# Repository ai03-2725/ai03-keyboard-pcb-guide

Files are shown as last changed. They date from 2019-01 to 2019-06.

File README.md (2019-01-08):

# ai03's Keyboard PCB guide

* The guide covers everything from installing KiCad to producing the PCB.
* [Read it here](https://kbwiki.ai03.me/books/pcb-design/chapter/pcb-designer-guide)

### Repo contents
The repository contains the latest version of a PCB built following the guide.
Feel free to take a look if you need some help.

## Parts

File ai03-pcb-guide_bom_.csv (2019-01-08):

Component | Description | Part | References | Value | Footprint | Quantity Per PCB | Datasheet
1 | Unpolarized capacitor | C_Small | C4 C5 C6 | 0.1uF | C_0805 | 3 | ~
2 | Unpolarized capacitor | C_Small | C7 | 10uF | C_0805 | 1 | ~
3 | Unpolarized capacitor | C_Small | C3 | 1uF | C_0805 | 1 | ~
4 | Unpolarized capacitor | C_Small | C1 C2 | 22pF | C_0805 | 2 | ~
5 | Diode, small symbol | D_Small | D1 D2 D3 D4 | SOD-123 | D_SOD-123 | 4 | ~
6 | resettable fuse, polymeric positive temperature coefficient (PPTC), small symbol | Polyfuse_Small | F1 | 500mA | Fuse_SMD1206_Reflow | 1 | ~
7 |  | MX-1U | MX1 MX2 MX3 MX4 | MX-1U | MX-1U | 4
8 | Resistor, small symbol | R_Small | R1 R4 | 10k | R_0805 | 2 | ~
9 | Resistor, small symbol | R_Small | R2 R3 | 22 | R_0805 | 2 | ~
10 | Push button switch, generic, two pins | SW_Push | SW1 | SW_Push | SKQG-1155865 | 1
11 | 16MHz, 16kB Flash, 1.25kB SRAM, 512B EEPROM, USB 2.0, TQFP-44 | ATmega32U4-AU | U1 | ATmega32U4-AU | TQFP-44_10x10mm_Pitch0.8mm | 1 | http://ww1.microchip.com/downloads/en/DeviceDoc/Atmel-7766-8-bit-AVR-ATmega16U4-32U4_Datasheet.pdf
12 |  | Molex-0548190589 | USB1 | Molex-0548190589 | Molex-0548190589-Assembly | 1
13 | Four pin crystal, two ground/package pins (pin2 and 4) small symbol | Crystal_GND24_Small | Y1 | 16MHz | Crystal_SMD_3225-4pin_3.2x2.5mm | 1 | ~
Component Groups: | 13
Component Count: | 24
Fitted Components: | 24
Number of PCBs: | 1
Total components: | 24
Schematic Version:
Schematic Date:
BoM Date: | 1/7/2019 21:46
Schematic Source:
KiCad Version: | Eeschema (5.0.0)

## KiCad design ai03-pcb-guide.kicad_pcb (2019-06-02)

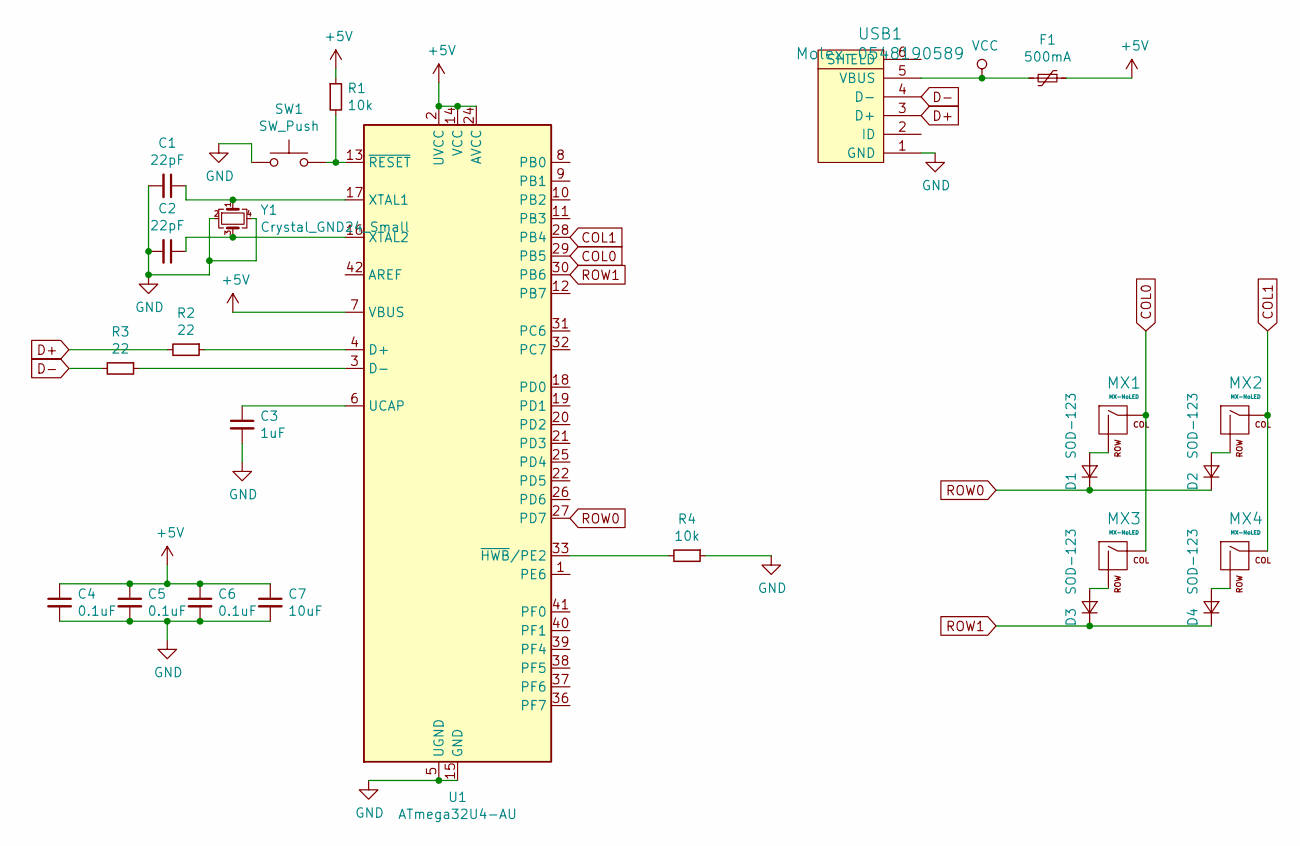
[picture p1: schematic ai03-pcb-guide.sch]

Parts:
C1, C2: 22pF; C_0805
C3: 1uF; C_0805
C4, C5, C6: 0.1uF; C_0805
C7: 10uF; C_0805
D1, D2, D3, D4: SOD-123; D_SOD-123
F1: 500mA; Fuse_SMD1206_Reflow
MX1, MX2, MX3, MX4: MX-NoLED; MX-1U
R1, R4: 10k; R_0805
R2, R3: 22; R_0805
SW1: SW_Push; SKQG-1155865
U1: ATmega32U4-AU; TQFP-44_10x10mm_Pitch0.8mm
USB1: Molex-0548190589; Molex-0548190589-Assembly
Y1: Crystal_GND24_Small; Crystal_SMD_3225-4pin_3.2x2.5mm

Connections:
+5V: C4.1, C5.1, C6.1, C7.1, F1.1, R1.1, U1.2 (UVCC), U1.7 (VBUS), U1.14 (VCC), U1.24 (AVCC), U1.34 (VCC), U1.44 (AVCC)
COL0: MX1.1 (COL), MX3.1 (COL), U1.29 (PB5)
COL1: MX2.1 (COL), MX4.1 (COL), U1.28 (PB4)
D+: R2.2, USB1.3 (D+)
D-: R3.2, USB1.4 (D-)
GND: C1.2, C2.2, C3.2, C4.2, C5.2, C6.2, C7.2, R4.1, SW1.1, U1.5 (UGND), U1.15 (GND), U1.23 (GND), U1.35 (GND), U1.43 (GND), USB1.1 (GND), Y1.2, Y1.4
unnamed: C1.1, U1.17 (XTAL1), Y1.1
unnamed: C2.1, U1.16 (XTAL2), Y1.3
unnamed: C3.1, U1.6 (UCAP)
unnamed: D1.2 (A), MX1.2 (ROW)
unnamed: D2.2 (A), MX2.2 (ROW)
unnamed: D3.2 (A), MX3.2 (ROW)
unnamed: D4.2 (A), MX4.2 (ROW)
unnamed: R1.2, SW1.2, U1.13 (~RESET)
unnamed: R2.1, U1.4 (D+)
unnamed: R3.1, U1.3 (D-)
unnamed: R4.2, U1.33 (~HWB~/PE2)
ROW0: D1.1 (K), D2.1 (K), U1.27 (PD7)
ROW1: D3.1 (K), D4.1 (K), U1.30 (PB6)
VCC: F1.2, USB1.5 (VBUS)

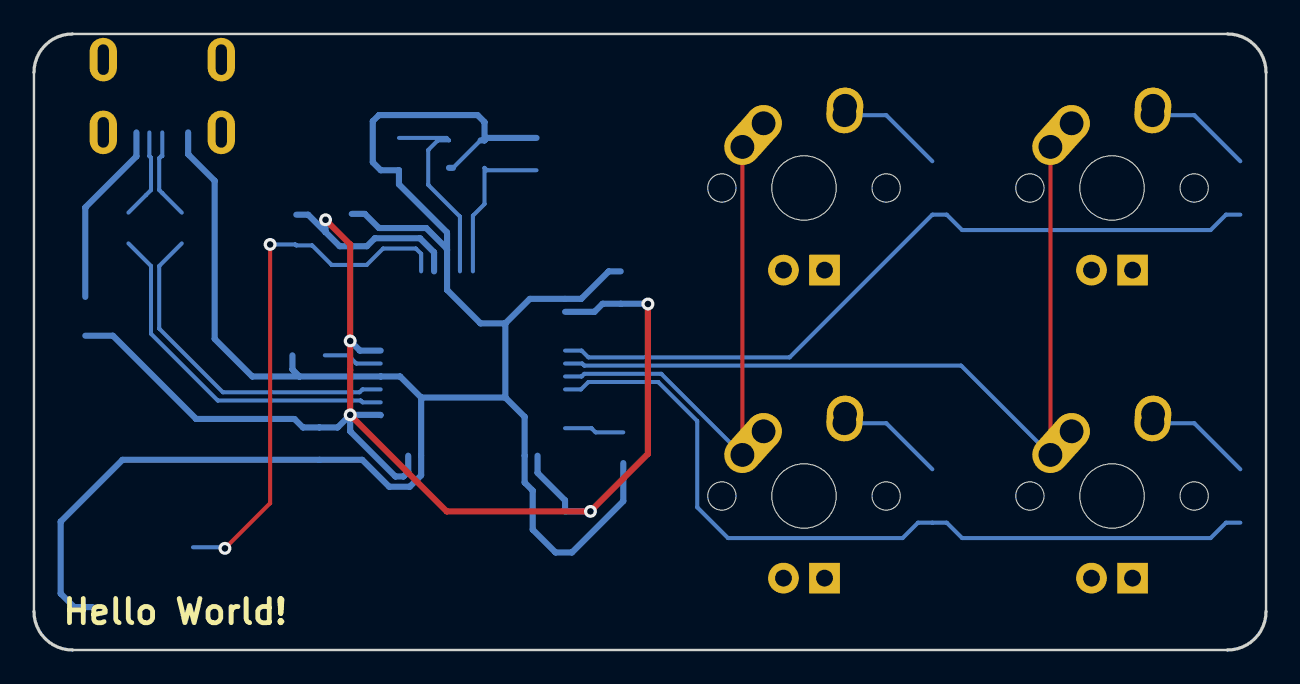
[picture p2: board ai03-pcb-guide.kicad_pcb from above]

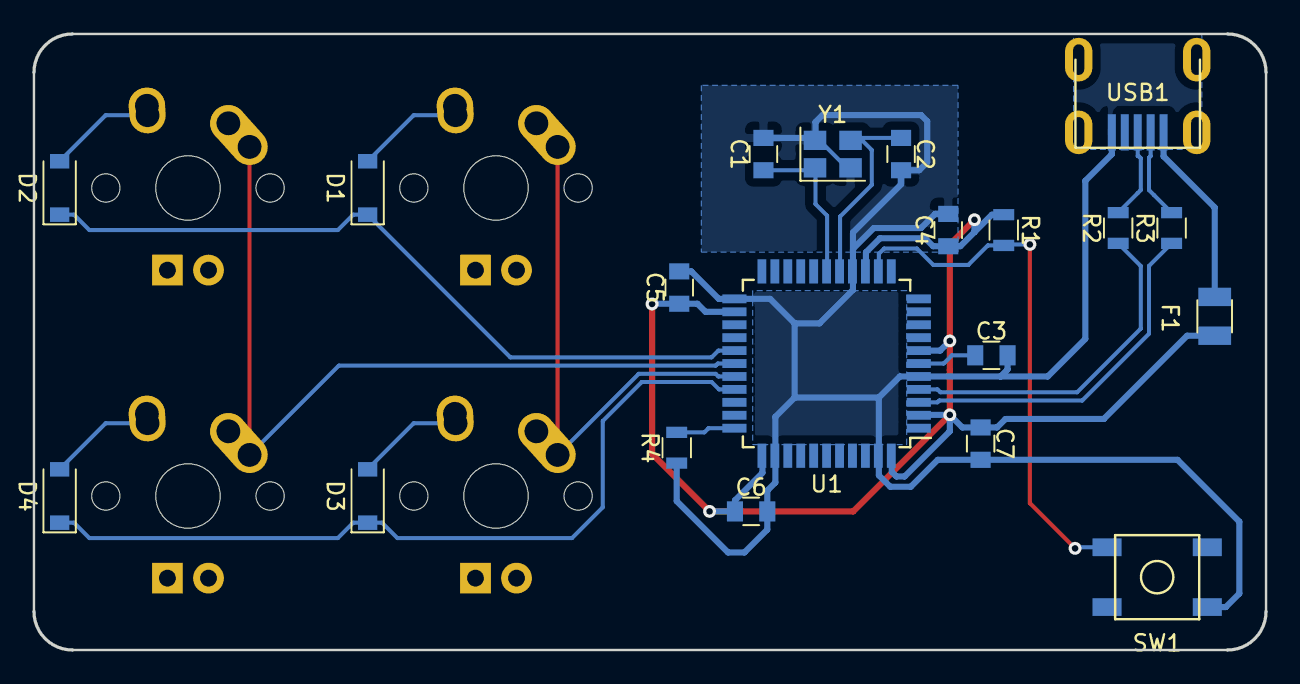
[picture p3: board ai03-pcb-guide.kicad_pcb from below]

Board: 2 copper layers, 76.2 x 38.1 mm, 24 parts (20 on the bottom side), 20 nets.

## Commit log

2019-01-07 Initialize project
    [ai03-pcb-guide.kicad_pcb, ai03-pcb-guide.sch]
2019-01-08 Add footprint libraries
2019-01-08 Route PCB
    [ai03-pcb-guide.sch]
2019-01-08 Generate gerbers
    [ai03-pcb-guide-B.Cu.gbl, ai03-pcb-guide-B.Mask.gbs, ai03-pcb-guide-B.SilkS.gbo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]
2019-01-08 Generate BOM
    [ai03-pcb-guide.kicad_pcb, ai03-pcb-guide_bom_.csv]
2019-05-27 Update to KiCad 5.1.2 guide data
    [ai03-pcb-guide.sch]
2019-06-02 Update PCB for revised guide
    [ai03-pcb-guide-B.Cu.gbl, ai03-pcb-guide-B.Mask.gbs, ai03-pcb-guide-B_Cu.gbl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]
2019-06-02 New gerbers
    [ai03-pcb-guide-B.Cu.gbl, ai03-pcb-guide-B.Mask.gbs, ai03-pcb-guide-B.SilkS.gbo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]
